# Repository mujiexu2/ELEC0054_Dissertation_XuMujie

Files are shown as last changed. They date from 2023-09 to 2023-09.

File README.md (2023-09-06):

# Bespoke Wearable IMU Device
This wearable system aims to be cost-effective, lightweight and compact size.
This project is separated in two sections done in parallel, prototyping and PCB Design. The STM32 board programming is 
done in STM32CubeIDE, schematics done in KiCad, PCB done in DipTrace, API run in Python(Vscode).

For communication, we have used SPI protocol in MCU & IMU communication, QSPI protocol in Memory & MCU communication, 
USB transmission in Board & PC communication.

STML412CBT6 communicates with ICM-20948 with SPI, communicates with the Memory module with
QSPI, USB interface designed on board is responsible for transmit data to the PC and
present on the API.

Due to time constraints, the PCB file has not been updated to match the version of the schematics file.
The PCB board has been tested to have the low power characteristics, with 0.121W. Using YOJOCK USB C Tester Power Meter.

## Prototype
- NUCLEO-L412RB-P (STM32 Nucleo-64 development board with STM32L412RB MCU, SMPS, supports Arduino, ST Morpho connectivity)
- SparkFun 9DoF IMU (ICM-20948) Breakout Board
- MT25QL512ABB-based self-made Flash Memory Breakout Board
- Adafruit USB Micro-B Breakout Board
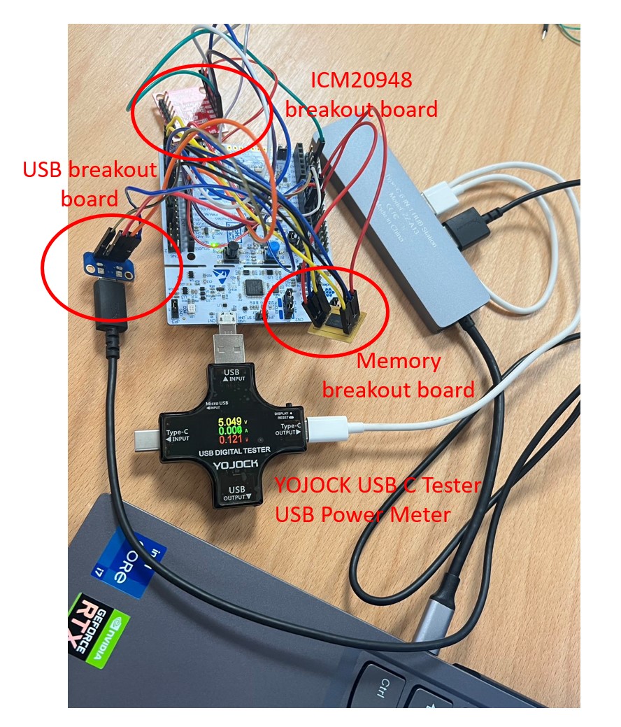
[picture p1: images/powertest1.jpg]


## PCB Design (size: 50.961mm x 43.929mm)
Component List:
- InvenSense ICM20948 (World's Lowest-Power 9‑Axis MEMS MotionTracking® Device)
- STM32L412CBT6 (Ultra-low-power Arm® Cortex®-M4 32-bit MCU+FPU)
- MT25QL512ABB (Serial NOR Flash Memory)
- USB Connector, Micro USB Type B
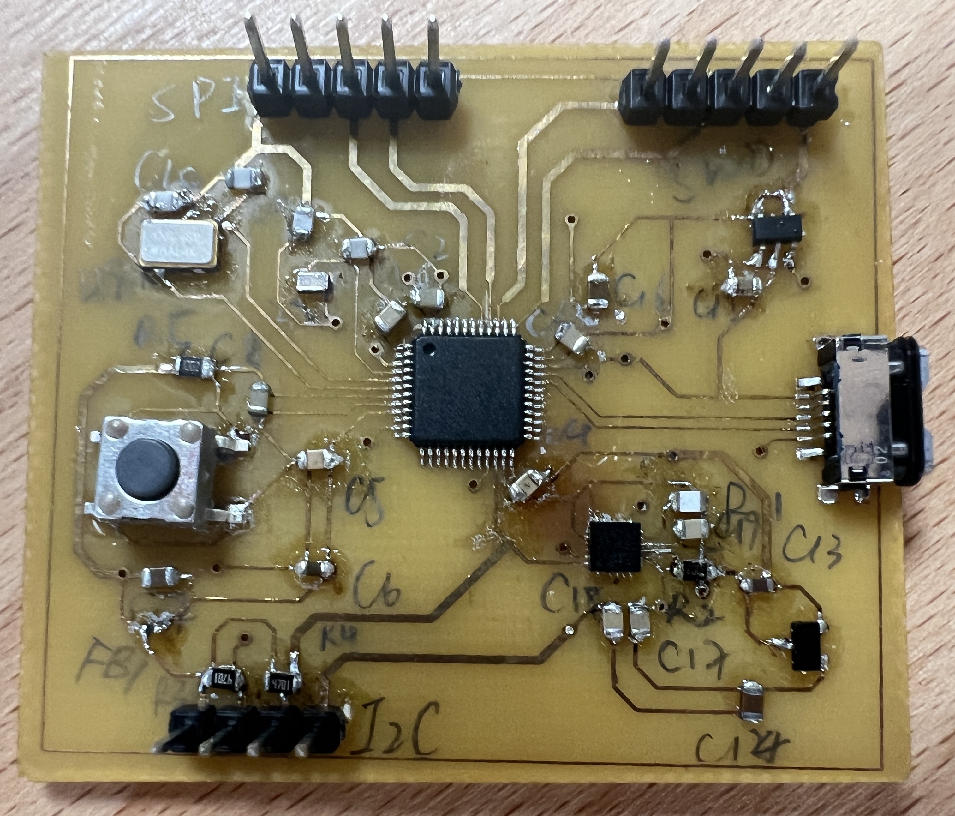
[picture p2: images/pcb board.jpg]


## Component List:
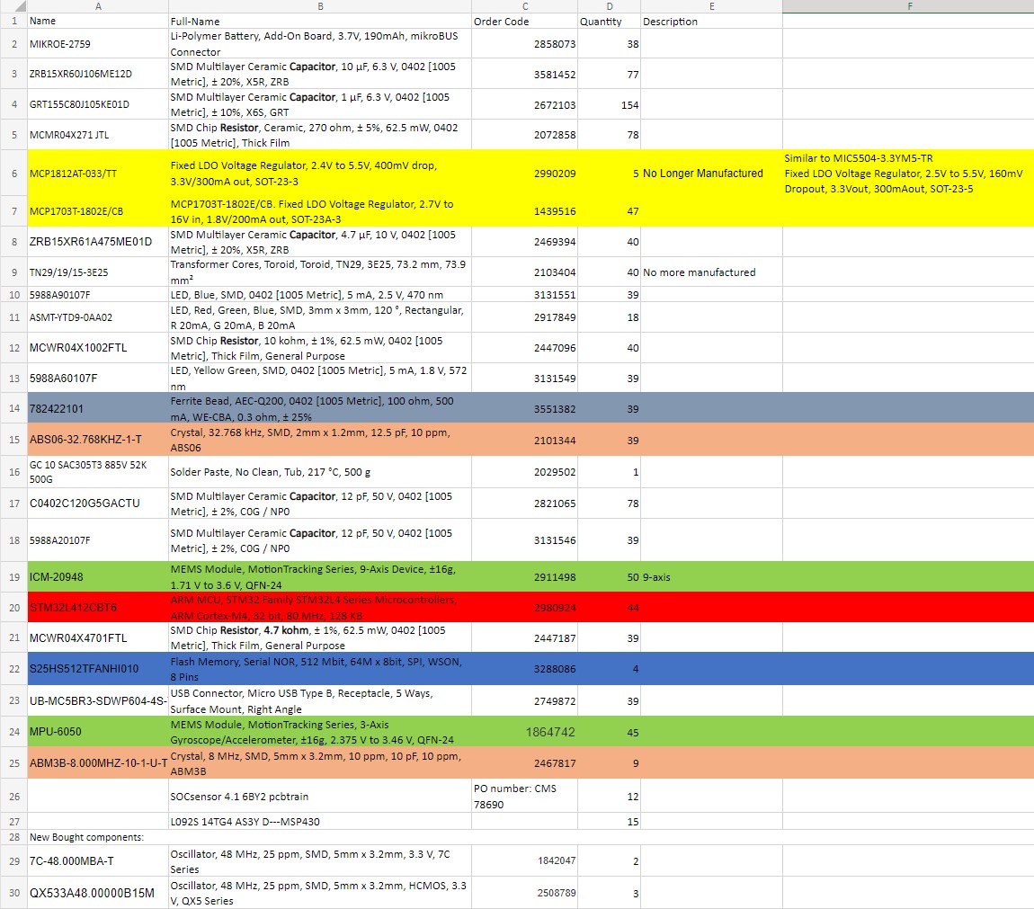
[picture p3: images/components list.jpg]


## File Description
### ICM_SPI_rtc(STM32CubeIDE programs):
- icm20948.c: Read accelerometer(unit: g), gyroscope(units: dps) and magnetometer(units: uT) data
- time.c: Get UTC time, current local UK time, elapsed time
- main.c: Combined time data and sensor data, and sent to USB VCP for future analysis

#### STM32CubeIDE SPI configuration
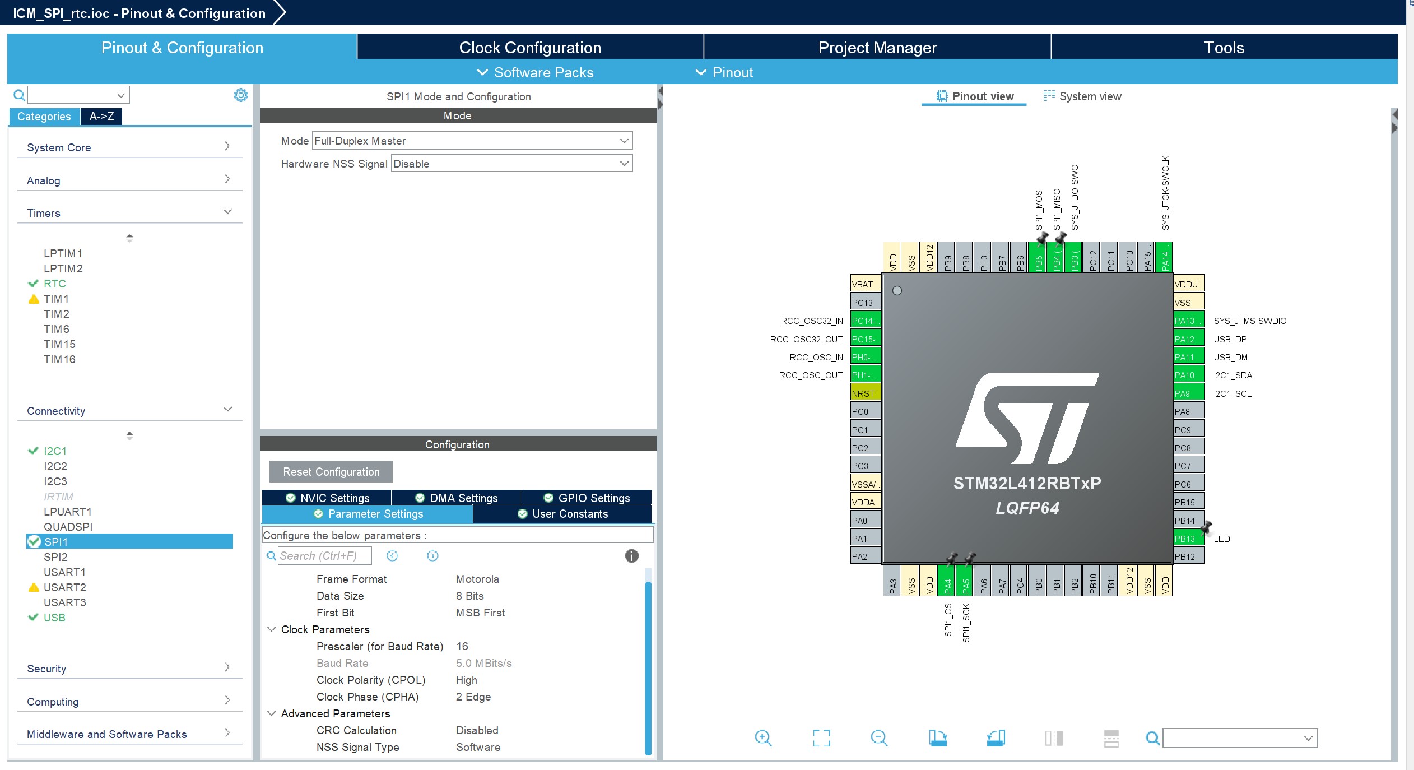
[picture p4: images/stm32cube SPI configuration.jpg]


#### STM32CubeIDE USB + USB Device configuration
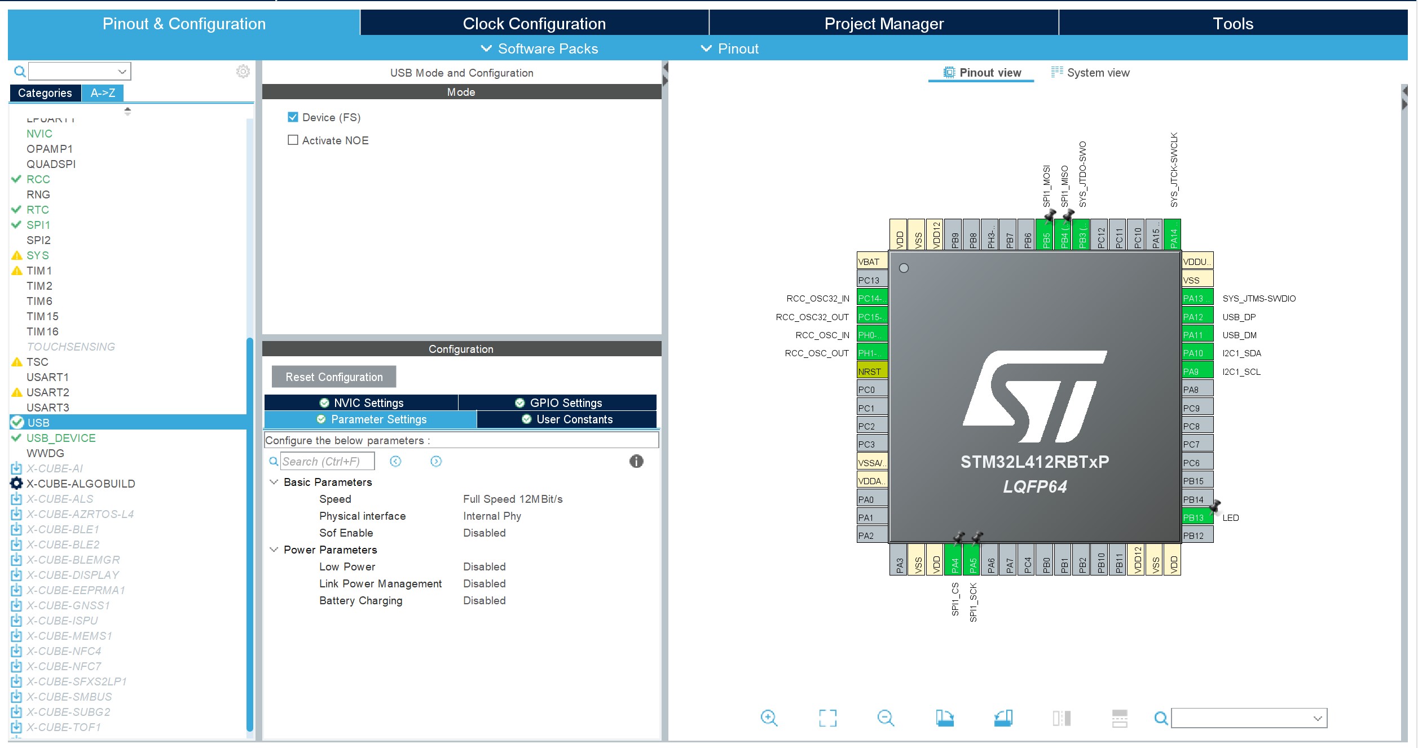
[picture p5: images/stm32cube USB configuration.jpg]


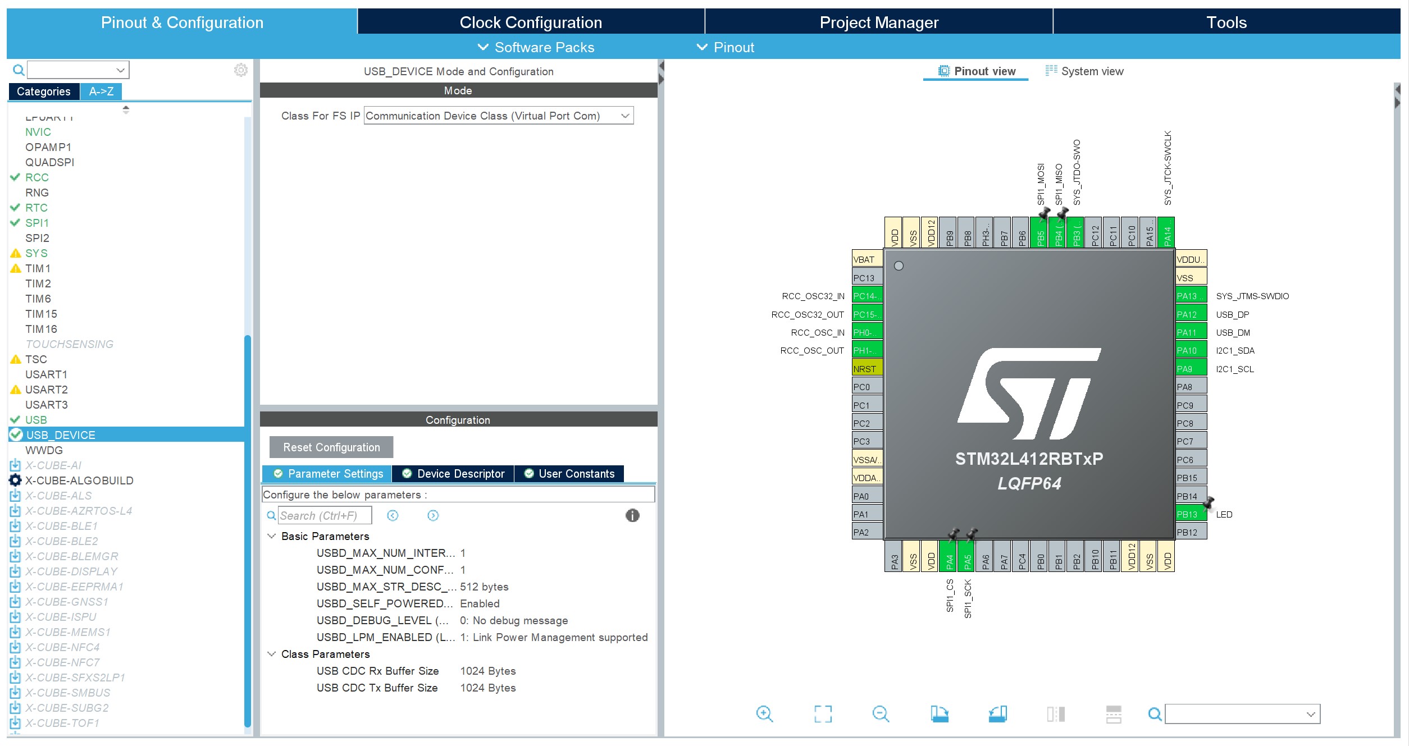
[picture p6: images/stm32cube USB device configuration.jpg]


#### STM32CubeIDE RTC configuration
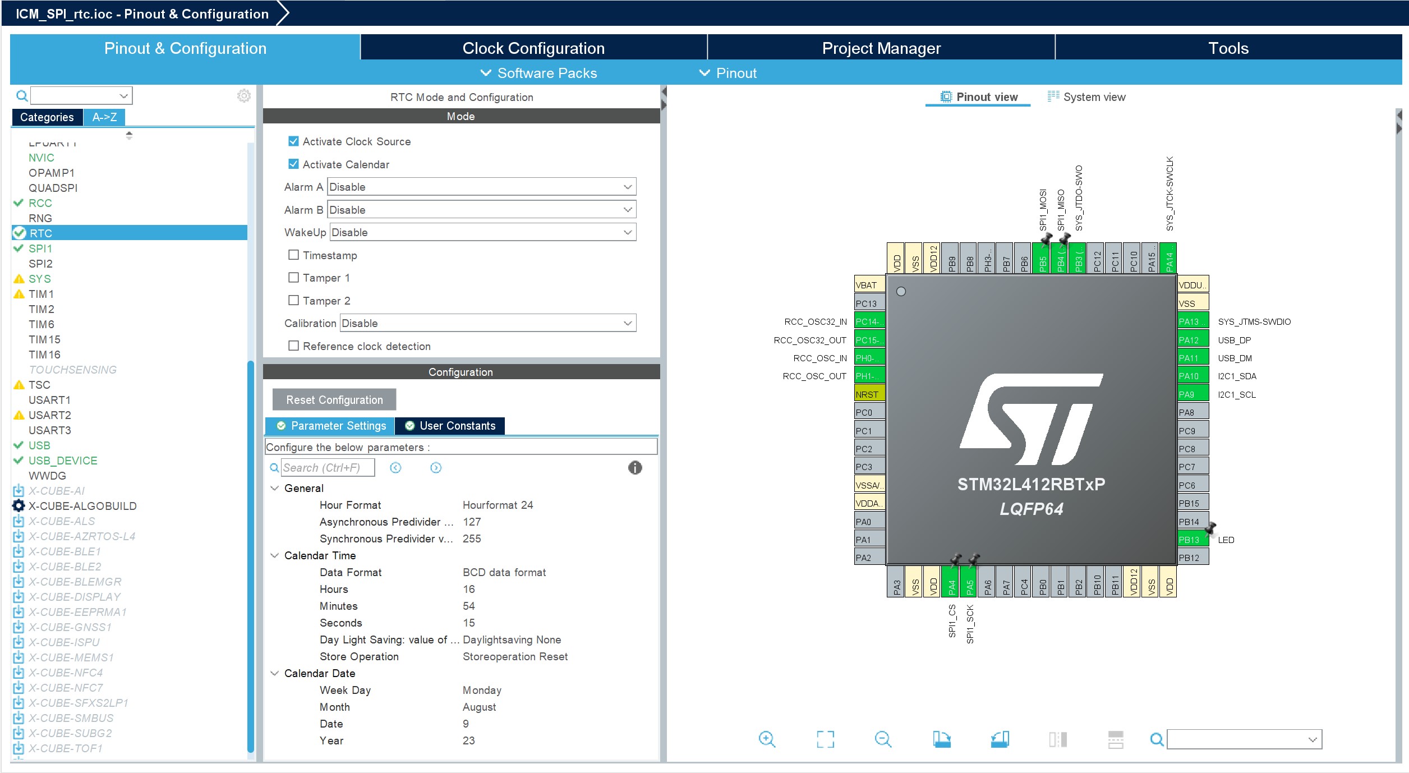
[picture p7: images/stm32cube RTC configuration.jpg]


### PCB(DipTrace files):
- PCB-Xu Mujie-0614.dip: The PCB Diptrace file for assembled PCB board
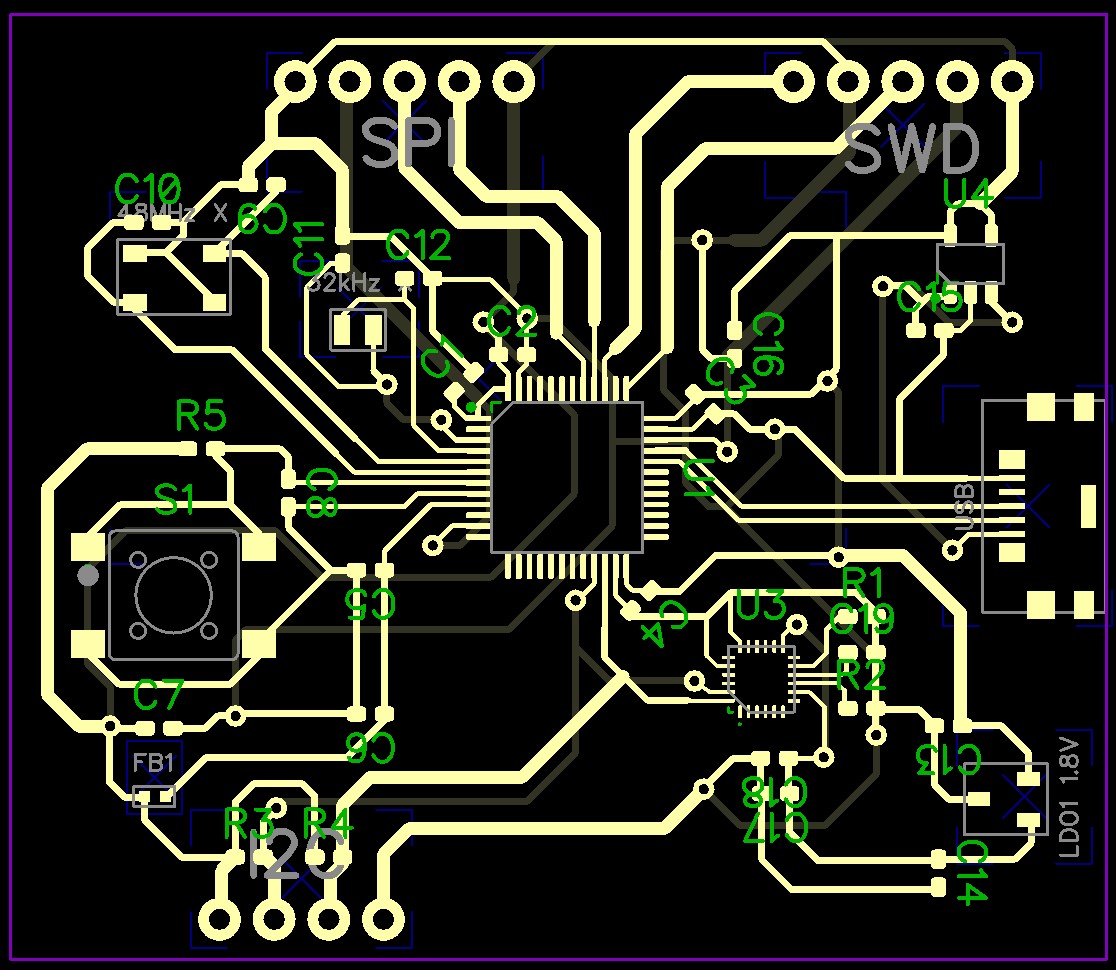
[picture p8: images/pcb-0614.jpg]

- PCB-Xu Mujie-spi-0815.dip: The newest PCB Diptrace file
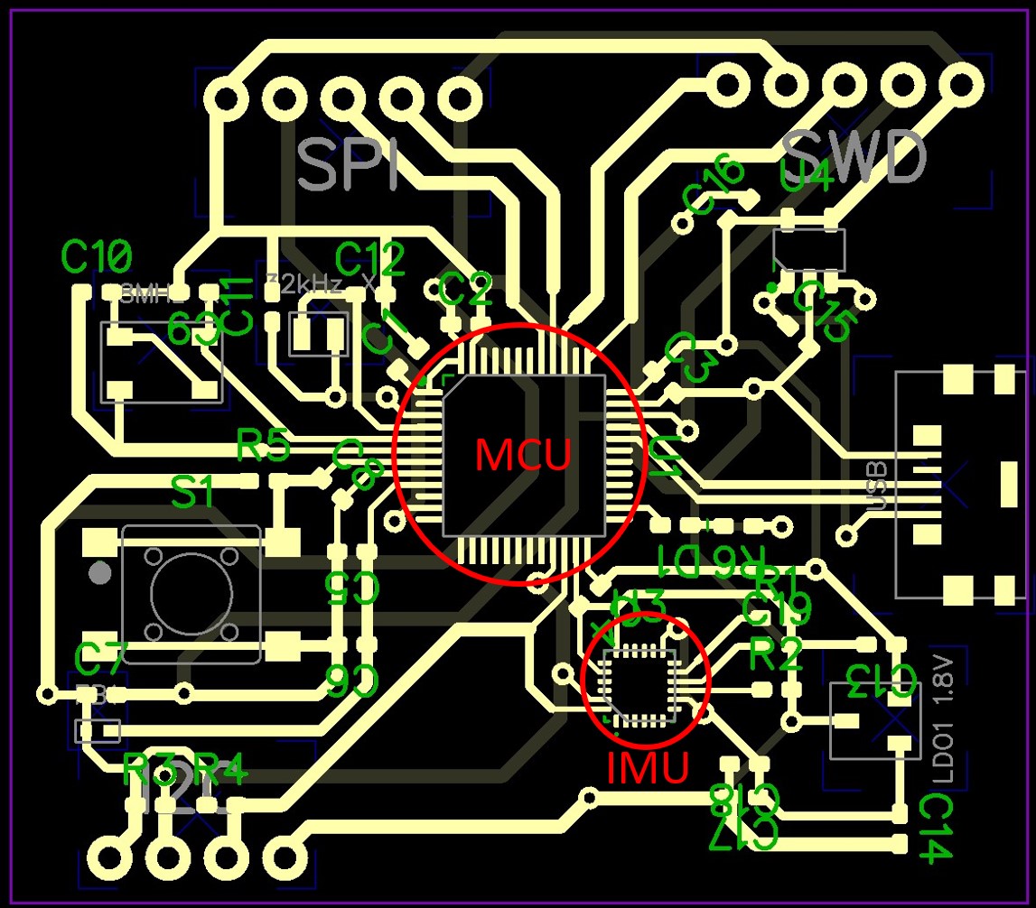
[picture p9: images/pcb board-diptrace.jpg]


### python API(python .py/.ipynb)
- time.c/time.ipynb:
  - receive data(time and sensor data) transmitted from the USB VCP
  - split data and save as .csv file in local directory
  - The csv file stored in the format:
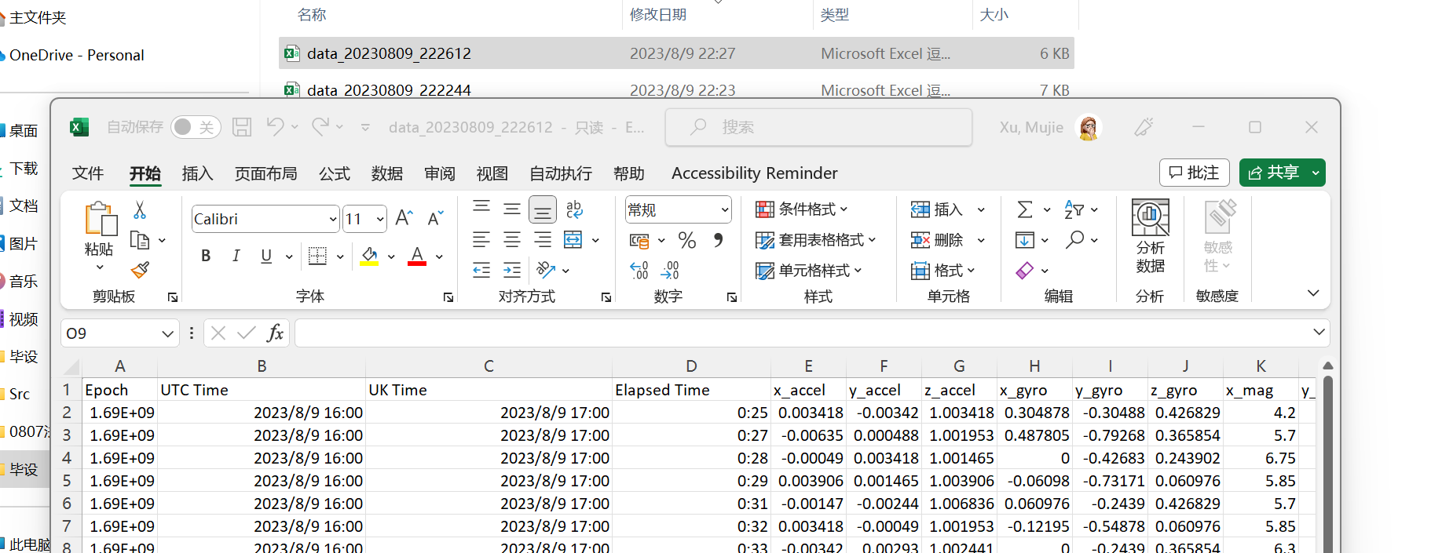
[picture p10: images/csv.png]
    

### schematics(KiCad file)
- 1_nrst.kicad_sch: circuits schematic up to date version
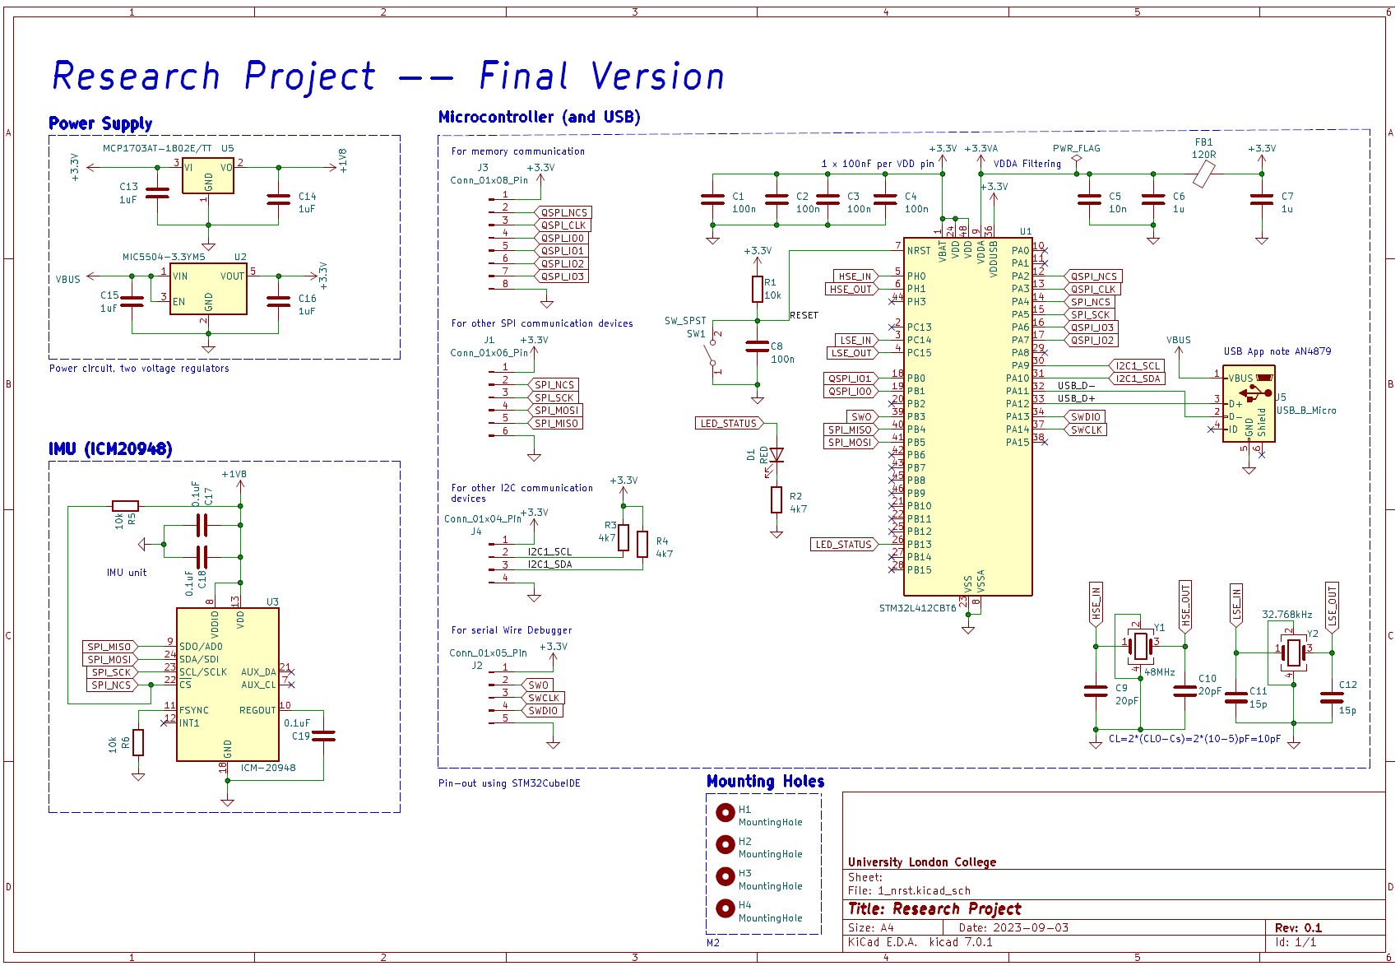
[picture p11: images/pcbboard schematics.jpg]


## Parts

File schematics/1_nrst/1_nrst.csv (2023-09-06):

Source: | C:\Users\xmj_j\Desktop\研究生\毕设\1\1.kicad_sch
Date: | 3/27/2023 5:25:18 AM
Tool: | Eeschema 7.0.1
Generator: | C:\Program Files\KiCad\7.0\bin\scripting\plugins/bom_csv_grouped_by_value_with_fp.py
Component Count: | 28
Ref | Qnty | Value | Cmp name | Footprint | Description | Vendor | DNP
C1, C2 | 2 | 22u | C | Capacitor_SMD:C_0805_2012Metric | Unpolarized capacitor
C3 | 1 | 10u | C | Capacitor_SMD:C_0603_1608Metric | Unpolarized capacitor
C4, C5, C6 | 3 | 100n | C | Capacitor_SMD:C_01005_0402Metric | Unpolarized capacitor
C7 | 1 | 10n | C | Capacitor_SMD:C_0402_1005Metric | Unpolarized capacitor
C8, C9 | 2 | 1u | C | Capacitor_SMD:C_0402_1005Metric | Unpolarized capacitor
C10 | 1 | 100n | C | Capacitor_SMD:C_0402_1005Metric | Unpolarized capacitor
C11, C12 | 2 | 10p | C | Capacitor_SMD:C_0402_1005Metric | Unpolarized capacitor
D1 | 1 | RED | LED | LED_SMD:LED_0603_1608Metric | Light emitting diode
FB1 | 1 | 120R | FerriteBead | Inductor_SMD:L_0603_1608Metric | Ferrite bead
H1, H2, H3, H4 | 4 | MountingHole | MountingHole | MountingHole:MountingHole_2.2mm_M2 | Mounting Hole without connection
J1 | 1 | USB_B_Micro | USB_B_Micro | Connector_USB:USB_Micro-B_Wuerth_629105150521 | USB Micro Type B connector
J2, J3, J4 | 3 | Conn_01x04_Pin | Conn_01x04_Pin | Connector_PinHeader_2.54mm:PinHeader_1x04_P2.54mm_Vertical | Generic connector, single row, 01x04, script generated
R1, R2, R3 | 3 | 1k5 | R | Resistor_SMD:R_0402_1005Metric | Resistor
U1 | 1 | STM32L412CBT6 | STM32L412CBTx | Package_QFP:LQFP-48_7x7mm_P0.5mm | STMicroelectronics Arm Cortex-M4 MCU, 128KB flash, 40KB RAM, 80 MHz, 1.71-3.6V, 38 GPIO, LQFP48
U2 | 1 | AMS1117-3.3 | AMS1117-3.3 | Package_TO_SOT_SMD:SOT-223-3_TabPin2 | 1A Low Dropout regulator, positive, 3.3V fixed output, SOT-223
Y1 | 1 | 16MHz | Crystal_GND24 | Crystal:Crystal_SMD_3225-4Pin_3.2x2.5mm | Four pin crystal, GND on pins 2 and 4

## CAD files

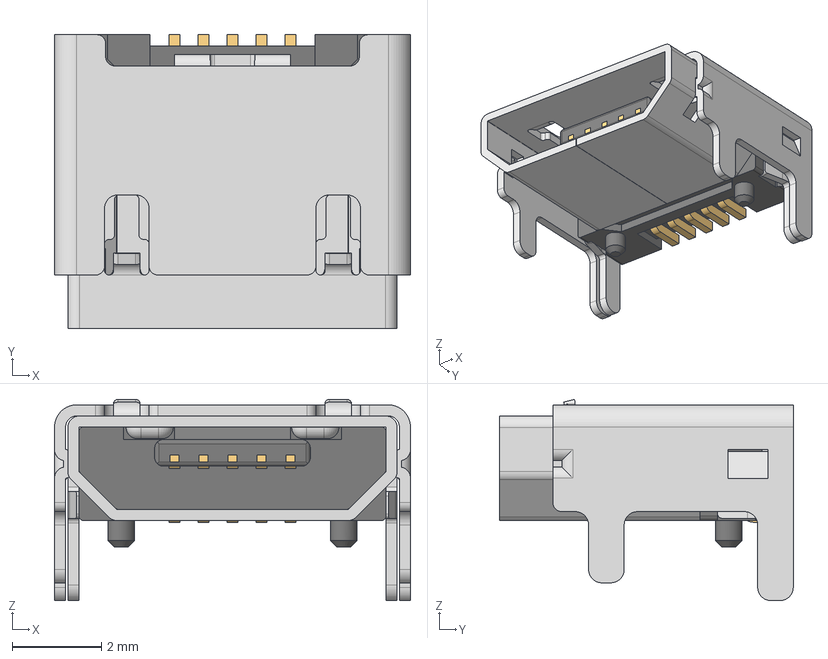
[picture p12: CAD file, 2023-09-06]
schematics/1_nrst/629105150521 (rev1).stp
8.00 x 6.60 x 4.52 mm
629105150521_Housing
629105150521_Pin1 x 4
629105150521_Pin2
629105150521_Shielding2
629105150521_Shielding

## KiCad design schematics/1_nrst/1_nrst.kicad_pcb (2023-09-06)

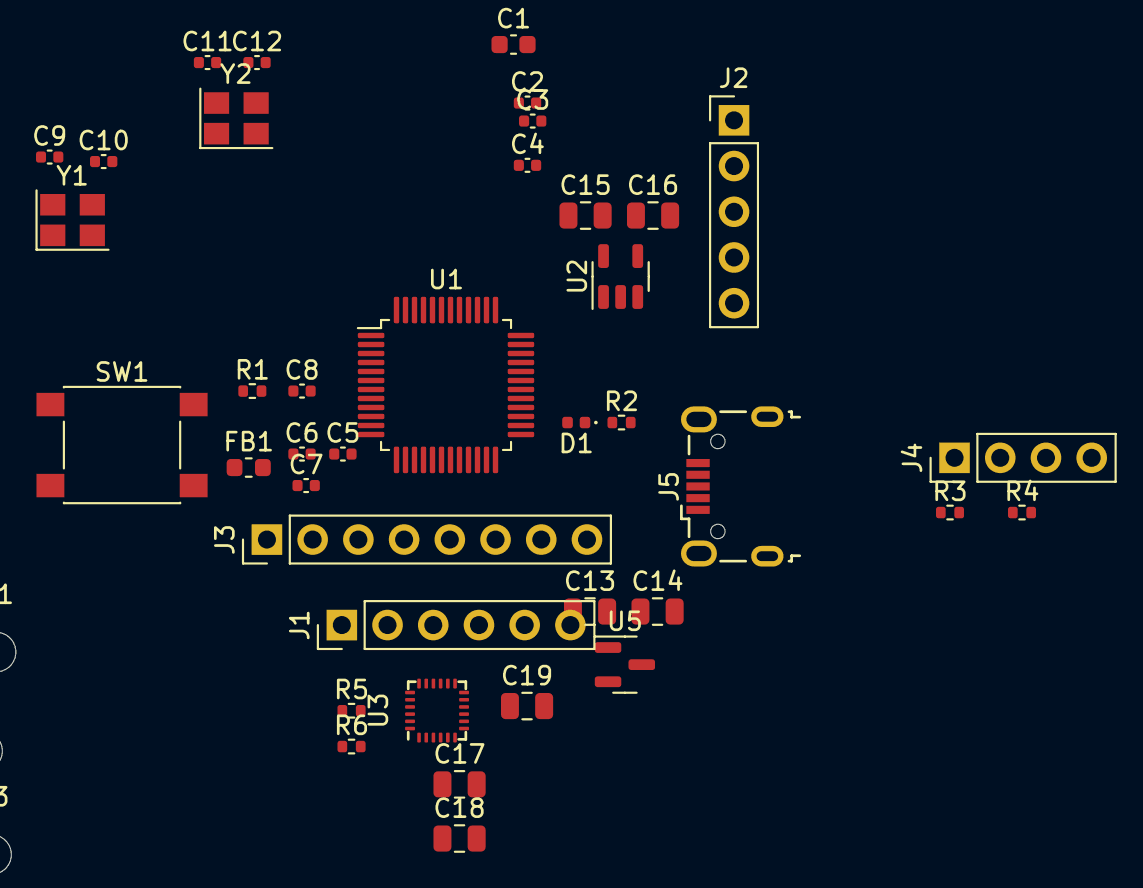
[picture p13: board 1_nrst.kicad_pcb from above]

Board: 2 copper layers, 43 parts (0 on the bottom side), 31 nets, no tracks yet.

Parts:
C1: 10u; C_0603_1608Metric
C2, C3, C4, C8: 100n; C_0402_1005Metric
C5: 10n; C_0402_1005Metric
C6, C7: 1u; C_0402_1005Metric
C9, C10: 10p; C_0402_1005Metric
C11, C12: 15p; C_0402_1005Metric
C13, C14, C15, C16: 1uF; C_0805_2012Metric
C17, C18, C19: 0.1uF; C_0805_2012Metric
D1: RED; LED_0402_1005Metric
FB1: 120R; L_0603_1608Metric
H1, H2, H3, H4: MountingHole; MountingHole_2.2mm_M2
J1: Conn_01x06_Pin; PinHeader_1x06_P2.54mm_Vertical
J2: Conn_01x05_Pin; PinHeader_1x05_P2.54mm_Vertical
J3: Conn_01x08_Pin; PinHeader_1x08_P2.54mm_Vertical
J4: Conn_01x04_Pin; PinHeader_1x04_P2.54mm_Vertical
J5: USB_B_Micro; USB_Micro-B_Wuerth_629105150521
R1, R5, R6: 10k; R_0402_1005Metric
R2, R3, R4: 4k7; R_0402_1005Metric
SW1: SW_SPST; SW_SPST_PTS645
U1: STM32L412CBT6; LQFP-48_7x7mm_P0.5mm
U2: MIC5504-3.3YM5; SOT-23-5
U3: ICM-20948; InvenSense_QFN-24_3x3mm_P0.4mm
U5: MCP1703AT-1802E/TT; SOT-23
Y1: 48MHz; Crystal_SMD_3225-4Pin_3.2x2.5mm
Y2: 32.786kHz; Crystal_SMD_3225-4Pin_3.2x2.5mm

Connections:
+1V8: C14.1, C17.1, C18.1, R5.1, U3.8 (VDDIO), U3.13 (VDD), U5.2 (VO)
+3.3V: C1.1, C2.1, C3.1, C4.1, C7.1, C13.1, C16.1, FB1.2, J1.1, J2.5, J3.1, J4.1, R1.1, R3.1, R4.1, U1.1 (VBAT), U1.24 (VDD), U1.36 (VDDUSB), U1.48 (VDD), U2.5 (VOUT), U5.3 (VI)
+3.3VA: C5.1, C6.1, FB1.1, U1.9 (VDDA)
/RESET: C8.1, R1.2, SW1.2 (B), U1.7 (NRST)
/SWCLK: J2.3, U1.37 (PA14)
/SWDIO: J2.4, U1.34 (PA13)
/USB_D+: J5.3 (D+), U1.33 (PA12)
/USB_D-: J5.2 (D-), U1.32 (PA11)
GND: C1.2, C2.2, C3.2, C4.2, C5.2, C6.2, C7.2, C8.2, C9.2, C10.2, C11.2, C12.2, C13.2, C14.2, C15.2, C16.2, C17.2, C18.2, C19.1, J1.6, J2.1, J3.8, J4.4, J5.5 (GND), R2.2, R6.1, SW1.1 (A), U1.8 (VSSA), U1.23 (VSS), U1.35 (VSS), U1.47 (VSS), U2.2 (GND), U3.18 (GND), U3.20 (GND), U5.1 (GND), Y1.2, Y1.4, Y2.2, Y2.4
HSE_IN: C9.1, U1.5 (PH0), Y1.1
HSE_OUT: C10.1, U1.6 (PH1), Y1.3
I2C1_SCL: J4.2, R3.2, U1.30 (PA9)
I2C1_SDA: J4.3, R4.2, U1.31 (PA10)
LED_STATUS: D1.2 (A), U1.26 (PB13)
LSE_IN: C11.1, U1.3 (PC14), Y2.1
LSE_OUT: C12.1, U1.4 (PC15), Y2.3
unnamed: D1.1 (K), R2.1
unnamed: R6.2, U3.11 (FSYNC)
unnamed: C19.2, U3.10 (REGOUT)
QSPI_CLK: J3.3, U1.13 (PA3)
QSPI_IO0: J3.4, U1.19 (PB1)
QSPI_IO1: J3.5, U1.18 (PB0)
QSPI_IO2: J3.6, U1.17 (PA7)
QSPI_IO3: J3.7, U1.16 (PA6)
QSPI_NCS: J3.2, U1.12 (PA2)
SPI_MISO: J1.5, U1.40 (PB4), U3.9 (SDO/AD0)
SPI_MOSI: J1.4, U1.41 (PB5), U3.24 (SDA/SDI)
SPI_NCS: J1.2, R5.2, U1.14 (PA4), U3.22 (~CS)
SPI_SCK: J1.3, U1.15 (PA5), U3.23 (SCL/SCLK)
SWO: J2.2, U1.39 (PB3)
VBUS: C15.1, J5.1 (VBUS), U2.1 (VIN), U2.3 (EN)

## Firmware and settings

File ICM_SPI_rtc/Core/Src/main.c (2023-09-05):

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
/* Includes ------------------------------------------------------------------*/
#include "main.h"
#include "i2c.h"
#include "rtc.h"
#include "spi.h"
#include "usb_device.h"
#include "gpio.h"

/* USER CODE BEGIN Includes */
#include "icm20948.h"
#include "time.h"
#include "usbd_cdc_if.h"
#include <string.h>
#include <stdio.h>
/* USER CODE END Includes */


/* USER CODE BEGIN PV */
//initialize variables for storing imu data
axises my_gyro;
axises my_accel;
axises my_mag;

icm_20948_data imu_data;

//char usbd_ch;
//int Flag = 0;

//char buffer1[] = "You sent 1, get 1 back\r\n";
//char buffer2[] = "You sent 2, get 2 back\r\n";
//char buffer3[] = "You sent 3, get 3 back\r\n";

char received_data[1000];

char time[30];
char date[30];

RTC_TimeTypeDef sTime = {0};
RTC_DateTypeDef sDate = {0};

NMEA_Result NMEA_result;

//organized data for future sending, including the time data and sensor data
typedef struct {
    time_data time_info;
    icm_20948_data sensor_data;
} combined_data;


/* USER CODE END PV */

void SystemClock_Config(void);
/**
  * @brief  The application entry point.
  * @retval int
  */
int main(void)
{
  /* USER CODE BEGIN 1 */
	//initialize time data and sensor data
	icm_20948_data imu_data;
	time_data time_result;
	combined_data dataToSend;7
	//get start time for getting the elapsed time later
	uint32_t startTime = HAL_GetTick();
  /* USER CODE END 1 */

  /* MCU Configuration--------------------------------------------------------*/

  /* Reset of all peripherals, Initializes the Flash interface and the Systick. */
  HAL_Init();

  /* Configure the system clock */
  SystemClock_Config();

  /* Initialize all configured peripherals */
  MX_GPIO_Init();
  MX_I2C1_Init();
  MX_SPI1_Init();
  MX_USB_DEVICE_Init();
  MX_RTC_Init();
  /* USER CODE BEGIN 2 */
  //initialize ICM gyroscope, accelerometer and magnetometer peripherals and configuration
  icm20948_init();
  ak09916_init();

  /* USER CODE END 2 */

  /* Infinite loop */
  /* USER CODE BEGIN WHILE */
  while (1)
  {
    /* USER CODE END WHILE */

    /* USER CODE BEGIN 3 */
	// This segment fetches sensor data, combines it with time information,
	// formats it into a specific string format, and sends it over USB.
	  dataToSend.time_info = read_time(startTime); // Assume you already have the read_time function
	  dataToSend.sensor_data = read_all_data(); // Assume you have modified the read_all_data function as previously indicated

	  char buffer[512]; // suppose 512 bytes is big enough
	  // Creating a formatted string from the combined time and sensor data
	  // part to insert special character that enable future data splitting
	  sprintf(buffer,
			  "#%u&" //unix timestamp
			  "%04d-%02d-%02d %02d:%02d:%02d&" // utc_timestamp
			  "%04d-%02d-%02d %02d:%02d:%02d&" //
			  "%02u:%02u&"//
			  "x_accel = %f/y_accel = %f/z_accel = %f&"
			  "x_gyro = %f/y_gyro = %f/z_gyro =  %f&"
			  "x_mag = %f/y_mag = %f/z_mag = %f&\r\n",
			  dataToSend.time_info.unix_timestamp,

			  dataToSend.time_info.utc_time.year,
			  dataToSend.time_info.utc_time.month,
			  dataToSend.time_info.utc_time.date,
			  dataToSend.time_info.utc_time.hour,
			  dataToSend.time_info.utc_time.min,
			  dataToSend.time_info.utc_time.sec,

			  dataToSend.time_info.uk_time.year,
			  dataToSend.time_info.uk_time.month,
			  dataToSend.time_info.uk_time.date,
			  dataToSend.time_info.uk_time.hour,
			  dataToSend.time_info.uk_time.min,
			  dataToSend.time_info.uk_time.sec,

			  dataToSend.time_info.elapsed_minutes,
			  dataToSend.time_info.elapsed_seconds,

			  dataToSend.sensor_data.x_accel,
			  dataToSend.sensor_data.y_accel,
			  dataToSend.sensor_data.z_accel,

			  dataToSend.sensor_data.x_gyro,
			  dataToSend.sensor_data.y_gyro,
			  dataToSend.sensor_data.z_gyro,

			  dataToSend.sensor_data.x_magnet,
			  dataToSend.sensor_data.y_magnet,
			  dataToSend.sensor_data.z_magnet

	  );
	  //transmit to the USB VCP
	  CDC_Transmit_FS(buffer, strlen(buffer));



  }

  /* USER CODE END 3 */
}

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
/* USER CODE BEGIN 4 */
int _write(int file, char *ptr, int len)
{
	int DataIdx;

	for (DataIdx = 0; DataIdx < len; DataIdx++)
	{
		ITM_SendChar(*ptr++);
	}
	return len;
}
/* USER CODE END 4 */
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


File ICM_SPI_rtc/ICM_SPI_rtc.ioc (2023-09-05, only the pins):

Mcu.UserName=STM32L412RBTxP
PA10.Signal=I2C1_SDA
PA11.Signal=USB_DM
PA12.Signal=USB_DP
PA4.GPIO_Label=SPI1_CS
PA4.Signal=GPIO_Output
PA5.Signal=SPI1_SCK
PA9.Signal=I2C1_SCL
PB13.GPIO_Label=LED
PB13.Signal=GPIO_Output
PB5.Signal=SPI1_MOSI

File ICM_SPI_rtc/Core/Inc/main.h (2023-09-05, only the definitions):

#define SPI1_CS_Pin GPIO_PIN_4
#define SPI1_CS_GPIO_Port GPIOA
#define LED_Pin GPIO_PIN_13
#define LED_GPIO_Port GPIOB

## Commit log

2023-09-05 initial commmit: update STM32CubeIDE files
    [ICM_SPI Debug.cfg, ICM_SPI Release.cfg]
2023-09-05 schematic updated
    [1_nrst.kicad_sch]
2023-09-05 PCB updated
    [1_nrst.kicad_sch]
2023-09-05 comments prepared for STM32CubeIDE files

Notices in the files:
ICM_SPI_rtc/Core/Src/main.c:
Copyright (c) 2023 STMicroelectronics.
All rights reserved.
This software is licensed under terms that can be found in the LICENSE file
